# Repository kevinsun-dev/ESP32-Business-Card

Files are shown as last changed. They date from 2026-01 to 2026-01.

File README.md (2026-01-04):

# ESP32 Business Card Web Server

PCB Business Card

**A 0.8mm thick PCB business card that hosts its own website.**

This repository contains the KiCad hardware design files and the PlatformIO firmware source code for a custom PCB business card. The card features a built-in ESP32-C3 microcontroller, a PCB-edge USB-C connector, and enough flash memory to host a compressed version of my personal portfolio website.

**[Read the full write-up here.](https://kevinsun.dev/blog/pcb-business-card)**

## ⚡ Features

* **Self-Hosting:** Runs a full HTTP web server directly on the card.
* **Optimized:** Uses **LittleFS** and **GZIP compression** to serve a <14kB website with minimal latency.
* **Cost-Effective:** BOM target under **$5** using the ESP32-C3FH4.

## 🛠 Hardware Design

The hardware is designed around the **Espressif ESP32-C3FH4**, a RISC-V microcontroller with built-in 4MB flash, chosen for its low component count and ease of use.

### Key Specs

* **MCU:** ESP32-C3FH4 (RISC-V, 160MHz, WiFi/BLE)
* **Connector:** [PCB-Edge USB-C](https://github.com/AnasMalas/pcb-edge-usb-c) (Reversible)
* **PCB Thickness:** 0.8mm (Critical for USB-C fit)
* **Finish:** ENIG (Electroless Nickel Immersion Gold) for durability and aesthetics.

## 💻 Firmware

The firmware is built using **PlatformIO** with the **Arduino Framework** atop **ESP-IDF**.

### Key Capabilities

* **LittleFS Filesystem:** Decouples the website content from the C++ firmware logic.
* **GZIP Compression:** All web assets are pre-compressed (gzip) to reduce transmission size (~5kB) and load times.
* **OTA Updates:** The website and firmware can be updated wirelessly without plugging the card back into a programmer.
* **Dynamic Routing:** Automatically maps URLs (e.g., `/about`) to their corresponding compressed files (`/about.html.gz`).

## 🚀 Getting Started

### 1. Build the Hardware

Generate gerbers for your PCB using the KiCad files in this repository and assemble the components listed in the BOM.

### 2. Flash the Firmware

1. Install [PlatformIO](https://platformio.org/).
2. Clone this repository.
3. Connect the board via USB (hold the BOOT button while plugging in to enter bootloader mode).
4. Upload the firmware:
```bash
pio run --target upload
```

### 3. Upload the Website

The website files live in the `data/` folder. You must upload the filesystem image separately from the code.

```bash
# Compress your site and place in data/
# Then run:
pio run --target uploadfs
```

## 🌐 Live Demo

I've set up an ESP32 webserver hosting a mirror of my website 24/7.

* **Card Site:** [https://card.kevinsun.dev](https://card.kevinsun.dev)
* **Card Status:** [https://card.kevinsun.dev/status](https://www.google.com/url?sa=E&source=gmail&q=https://card.kevinsun.dev/status) (Tunneled via Cloudflare)

## 📄 License

* **Hardware:** Creative Commons Attribution-ShareAlike 4.0 (CC BY-SA 4.0)
* **Firmware:** MIT License

## 🙌 Credits & Inspiration

* **[mitxela](https://mitxela.com/projects/stylocard):** For the original StyloCard inspiration.
* **[Anas Malas](https://github.com/AnasMalas/pcb-edge-usb-c):** For the PCB-edge USB-C footprint design.
* **Kevin Sun:** Project Creator.

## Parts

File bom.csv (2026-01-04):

Comment | Designator | Footprint | LCSC
USBLC6-2SC6 | U3 | Package_TO_SOT_SMD:SOT-23-6
BOOT | SW2 | TS-1187A-B-A-B:SW_TS-1187A-B-A-B
5k1 | R1,R2,R3,R4,R6,R7 | Resistor_SMD:R_0402_1005Metric
100nF | C1,C2,C5,C6,C13,C14,C17,C18,C20 | Capacitor_SMD:C_0402_1005Metric
GPIO Breakout | J2 | Connector_PinHeader_2.54mm:PinHeader_1x08_P2.54mm_Vertical
10nF | C8 | Capacitor_SMD:C_0402_1005Metric
CPU | D3 | LED_SMD:LED_0603_1608Metric
1.5pF | C11,C12 | Capacitor_SMD:C_0402_1005Metric_Pad0.74x0.62mm_HandSolder
AMS1117-3.3 | U4 | Package_TO_SOT_SMD:SOT-223-3_TabPin2
2.4nH | L1 | Inductor_SMD:L_0402_1005Metric
2.4nH | L2,L3 | Inductor_SMD:L_0402_1005Metric_Pad0.77x0.64mm_HandSolder
WiFi | D2 | LED_SMD:LED_0603_1608Metric
12p | C9,C10 | Capacitor_SMD:C_0402_1005Metric
RESET | SW1 | TS-1187A-B-A-B:SW_TS-1187A-B-A-B
L327S400H11L | Y1 | Crystal:Crystal_SMD_3225-4Pin_3.2x2.5mm
1k | R5,R8,R9,R10 | Resistor_SMD:R_0402_1005Metric
10uF | C3,C15,C16 | Capacitor_SMD:C_0402_1005Metric
150pF | C19 | Capacitor_SMD:C_0402_1005Metric_Pad0.74x0.62mm_HandSolder
1uF | C4,C7 | Capacitor_SMD:C_0402_1005Metric
PWR | D1 | LED_SMD:LED_0603_1608Metric
ESP32-C3FH4 | U1 | Package_DFN_QFN:QFN-32-1EP_5x5mm_P0.5mm_EP3.7x3.7mm
NT3H2111W0FHKH | U2 | C710403:C710403

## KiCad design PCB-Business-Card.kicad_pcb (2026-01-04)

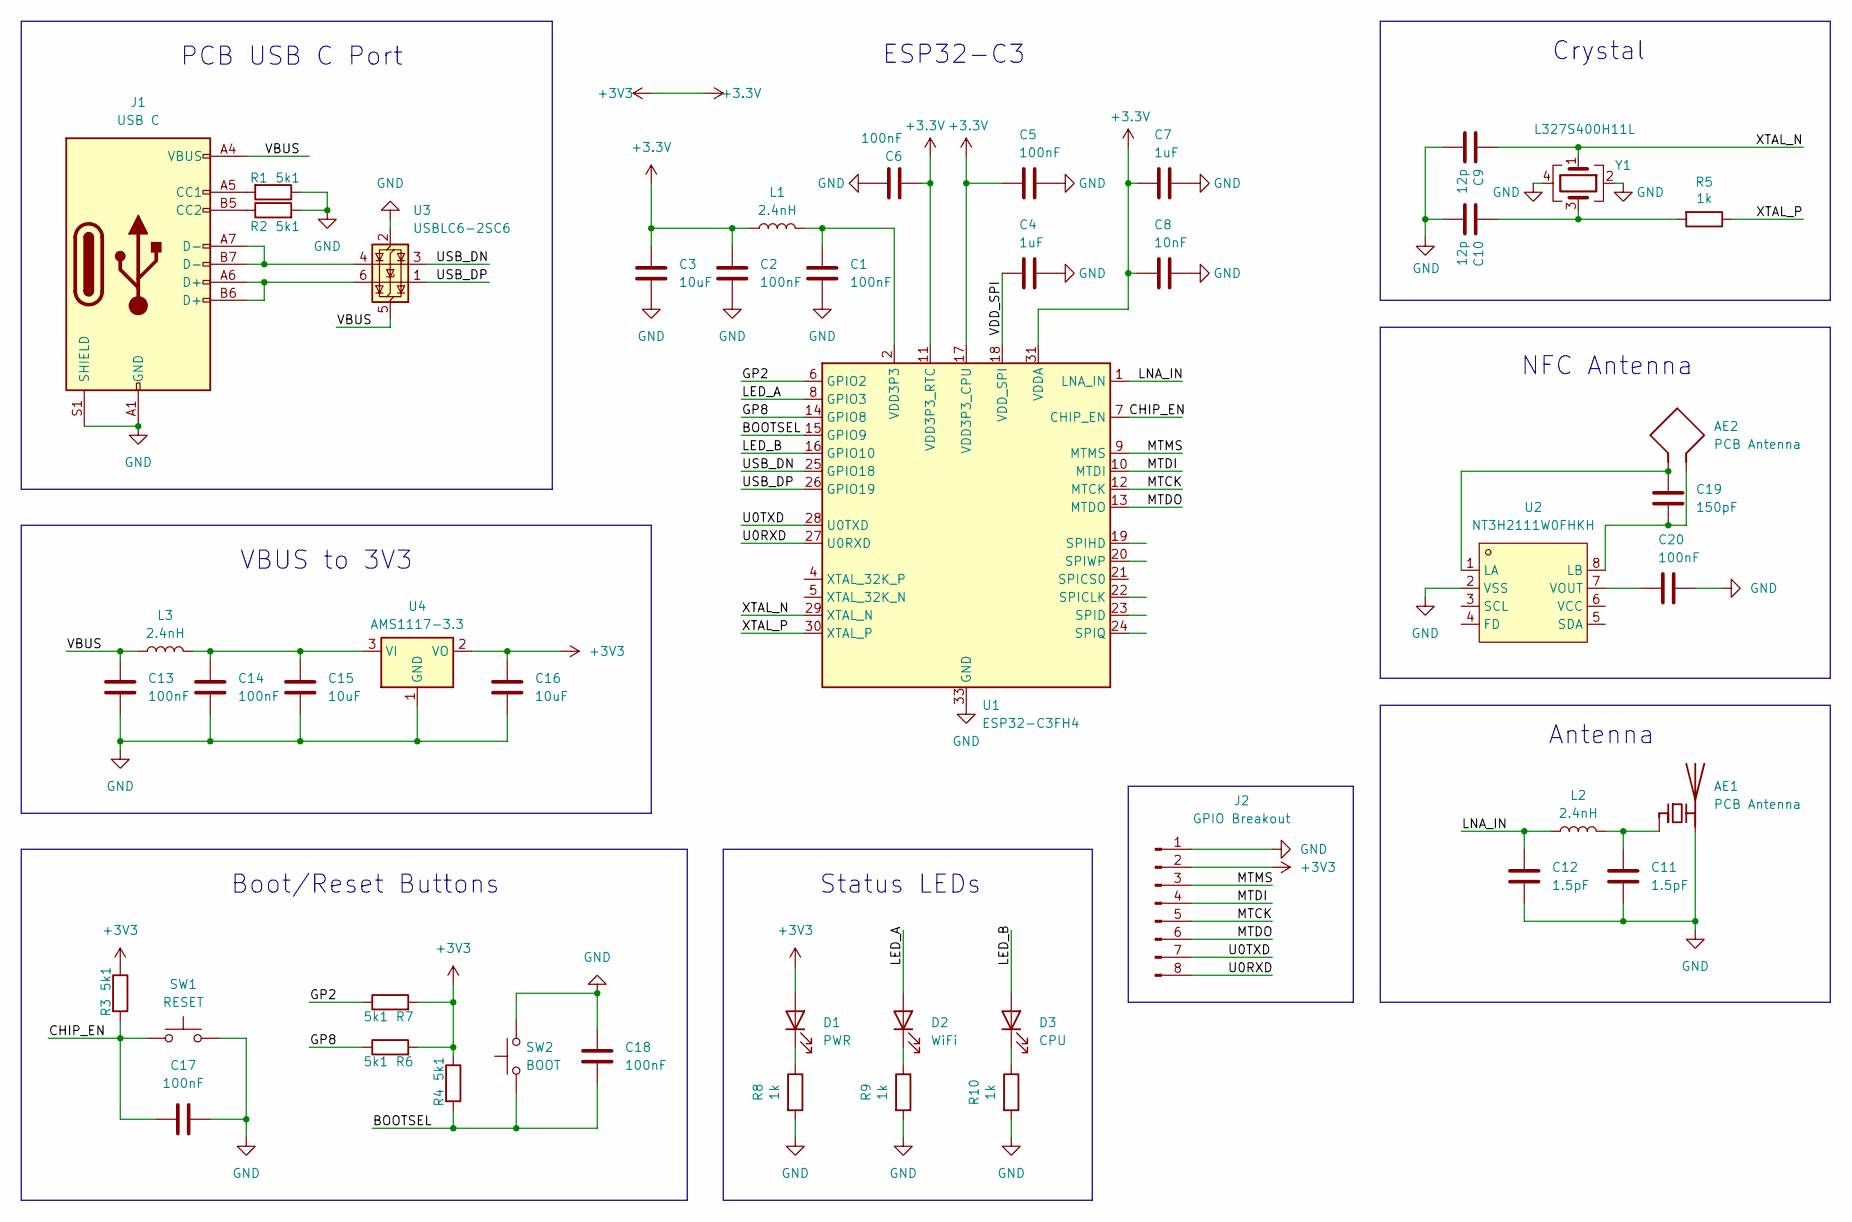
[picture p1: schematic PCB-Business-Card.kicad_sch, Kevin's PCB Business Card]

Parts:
AE1: PCB Antenna; pcb-antenna
AE2: PCB Antenna
C1, C2, C5, C6, C13, C14, C17, C18, C20: 100nF; C_0402_1005Metric; JLCPCB C1525
C3, C15, C16: 10uF; C_0402_1005Metric; JLCPCB C15525
C4, C7: 1uF; C_0402_1005Metric; JLCPCB C52923
C8: 10nF; C_0402_1005Metric; JLCPCB C15195
C9, C10: 12p; C_0402_1005Metric
C11, C12: 1.5pF; C_0402_1005Metric_Pad0.74x0.62mm_HandSolder; JLCPCB C1552
C19: 150pF; C_0402_1005Metric_Pad0.74x0.62mm_HandSolder
D1: PWR; LED_0603_1608Metric; JLCPCB C2286
D2: WiFi; LED_0603_1608Metric; JLCPCB C2290
D3: CPU; LED_0603_1608Metric; JLCPCB C89811
J1: USB C; PCBTypeC_24P
J2: GPIO Breakout; PinHeader_1x08_P2.54mm_Vertical
L1: 2.4nH; L_0402_1005Metric; JLCPCB C97997
L2, L3: 2.4nH; L_0402_1005Metric_Pad0.77x0.64mm_HandSolder; JLCPCB C97997
R1, R2, R3, R4, R6, R7: 5k1; R_0402_1005Metric; JLCPCB C25905
R5, R8, R9, R10: 1k; R_0402_1005Metric; JLCPCB C11702
SW1: RESET; SW_TS-1187A-B-A-B; JLCPCB C318884
SW2: BOOT; SW_TS-1187A-B-A-B; JLCPCB C318884
U1: ESP32-C3FH4; QFN-32-1EP_5x5mm_P0.5mm_EP3.7x3.7mm; JLCPCB C2858491
U2: NT3H2111W0FHKH; C710403; LCSC Part C710403
U3: USBLC6-2SC6; SOT-23-6; JLCPCB C2687116
U4: AMS1117-3.3; SOT-223-3_TabPin2; JLCPCB C6186
Y1: L327S400H11L; Crystal_SMD_3225-4Pin_3.2x2.5mm; JLCPCB C5261245

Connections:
+3.3V: C2.1, C3.1, C5.1, C6.1, C7.1, C8.1, C16.1, D1.2 (A), J2.2, L1.1, R3.1, R4.1, R6.2, R7.2, U1.11 (VDD3P3_RTC), U1.17 (VDD3P3_CPU), U1.31 (VDDA), U1.32 (VDDA), U4.2 (VO)
/BOOTSEL: C18.1, R4.2, SW2.1, U1.15 (GPIO9)
/CHIP_EN: C17.1, R3.2, SW1.1, U1.7 (CHIP_EN)
/GP2: R7.1, U1.6 (GPIO2)
/GP8: R6.1, U1.14 (GPIO8)
/LED_A: D2.2 (A), U1.8 (GPIO3)
/LED_B: D3.2 (A), U1.16 (GPIO10)
/LNA_IN: C12.1, L2.1, U1.1 (LNA_IN)
/MTCK: J2.5, U1.12 (MTCK)
/MTDI: J2.4, U1.10 (MTDI)
/MTDO: J2.6, U1.13 (MTDO)
/MTMS: J2.3, U1.9 (MTMS)
/U0RXD: J2.8, U1.27 (U0RXD)
/U0TXD: J2.7, U1.28 (U0TXD)
/USB_DN: U1.25 (GPIO18), U3.3 (I/O2)
/USB_DP: U1.26 (GPIO19), U3.1 (I/O1)
/VBUS: C13.1, J1.A4 (VBUS), J1.A9 (VBUS), J1.B4 (VBUS), J1.B9 (VBUS), L3.1, U3.5 (VBUS)
/VDD_SPI: C4.1, U1.18 (VDD_SPI)
/XTAL_N: C9.1, U1.29 (XTAL_N), Y1.1
/XTAL_P: R5.1, U1.30 (XTAL_P)
GND: AE1.2 (PCB_Trace), C1.2, C2.2, C3.2, C4.2, C5.2, C6.2, C7.2, C8.2, C9.2, C10.2, C11.2, C12.2, C13.2, C14.2, C15.2, C16.2, C17.2, C18.2, C20.2, J1.A1 (GND), J1.A12 (GND), J1.B1 (GND), J1.B12 (GND), J1.S1 (SHIELD), J2.1, R1.1, R2.2, R8.2, R9.2, R10.2, SW1.2, SW2.2, U1.33 (GND), U2.2 (VSS), U3.2 (GND), U4.1 (GND), Y1.2, Y1.4
unnamed: AE1.1 (FEED), C11.1, L2.2
unnamed: C1.1, L1.2, U1.2 (VDD3P3), U1.3 (VDD3P3)
unnamed: C10.1, R5.2, Y1.3
unnamed: D1.1 (K), R8.1
unnamed: D2.1 (K), R9.1
unnamed: D3.1 (K), R10.1
unnamed: J1.A5 (CC1), R1.2
unnamed: J1.B5 (CC2), R2.1
unnamed: J1.A6 (D+), J1.B6 (D+), U3.6 (I/O1)
unnamed: J1.A7 (D-), J1.B7 (D-), U3.4 (I/O2)
unnamed: AE2.1, C19.1, U2.1 (LA)
unnamed: AE2.2, C19.2, U2.8 (LB)
unnamed: C20.1, U2.7 (VOUT)
unnamed: C14.1, C15.1, L3.2, U4.3 (VI)

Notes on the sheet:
NFC Antenna
ESP32-C3
VBUS to 3V3
Crystal
Boot/Reset Buttons
PCB USB C Port
Status LEDs
Antenna

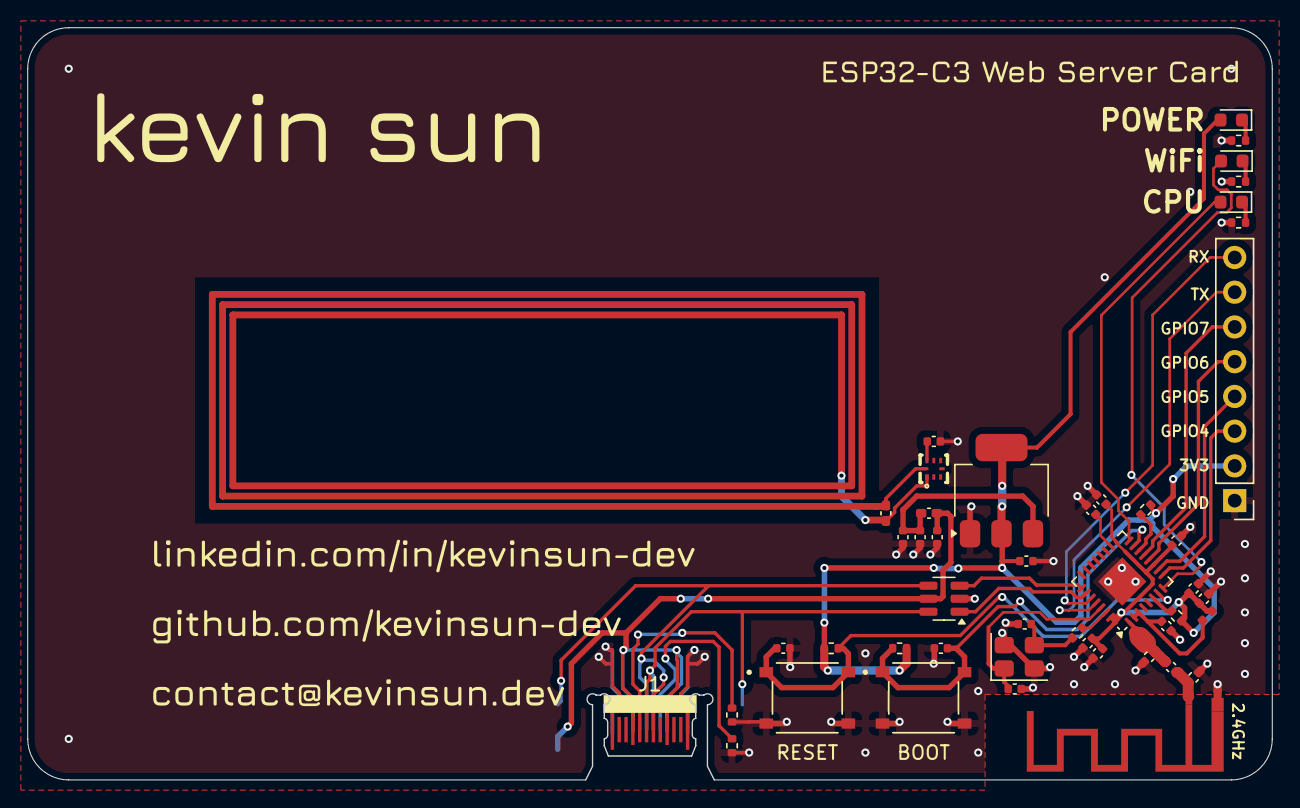
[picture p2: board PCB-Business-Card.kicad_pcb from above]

Board: 2 copper layers, 91.0 x 55.0 mm, 46 parts (0 on the bottom side), 35 nets.

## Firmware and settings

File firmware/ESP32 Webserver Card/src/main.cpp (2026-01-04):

#include <Arduino.h>
#include <ESPmDNS.h>
#include <LittleFS.h>
#include <NetworkClient.h>
#include <WebServer.h>
#include <WiFi.h>
#include <secrets.h>

const char* ssid = WIFI_SSID;
const char* password = WIFI_PWD;
const char* ota_secret = OTA_PWD;

WebServer server(80);
const int led = 13;

// --- PERSISTENCE SETTINGS ---
const char* STATS_FILE = "/stats.bin";
const unsigned long SAVE_INTERVAL_MS = 3600000;  // 1 Hour
unsigned long lastSaveTime = 0;

// Struct to hold data we want to save
struct PersistentStats {
    uint64_t totalVisits;  // 64-bit to prevent overflow
    uint64_t totalResponseTimeMs;
    uint64_t totalRuntimeSeconds;  // Cumulative time across all boots
};

PersistentStats stats = {0, 0, 0};

// Helper: Secure OTA Auth Check
bool isAuthorized() {
    if (server.arg("token") == ota_secret) return true;
    return false;
}

// Helper: Secure OTA Upload
File uploadFile;
bool uploadAccepted = false;

void handleFileUpload() {
  HTTPUpload& upload = server.upload();
  
  // 1. START
  if (upload.status == UPLOAD_FILE_START) {
    if (!isAuthorized()) {
      Serial.println("Unauthorized upload attempt blocked.");
      uploadAccepted = false;
      return;
    }

    String filename = upload.filename;
    if (!filename.startsWith("/")) filename = "/" + filename;
    Serial.print("Receiving file: "); Serial.println(filename);
    
    uploadFile = LittleFS.open(filename, "w");
    uploadAccepted = true;
    filename = String();
  } 
  
  // 2. WRITE (The Danger Zone)
  else if (upload.status == UPLOAD_FILE_WRITE) {
    if (uploadAccepted && uploadFile) {
      size_t bytesWritten = uploadFile.write(upload.buf, upload.currentSize);
      
      // CRITICAL CHECK: Did we actually write everything?
      if (bytesWritten != upload.currentSize) {
         Serial.println("Write Failed!");
         // Optional: Abort logic
      }
      
      // FIX: Feed the Watchdog!
      yield(); 
    }
  } 
  
  // 3. END
  else if (upload.status == UPLOAD_FILE_END) {
    if (uploadAccepted && uploadFile) {
      uploadFile.close();
      Serial.print("Upload Size: "); Serial.println(upload.totalSize);
      
      // Force a slight delay to ensure Serial finishes before any potential redirect logic
      delay(2); 
    }
  }
}

// Helper: Secure OTA Complete
void handleUploadResponse() {
    if (!isAuthorized()) {
        server.send(401, "text/plain", "Unauthorized");
    } else {
        server.sendHeader("Location", "/status");
        server.send(303);
    }
}

// Helper: Save to Flash
void saveStats() {
    File file = LittleFS.open(STATS_FILE, "w");
    if (!file) {
        Serial.println("Failed to open stats file for writing");
        return;
    }

    // Update the runtime before saving
    file.write((uint8_t*)&stats, sizeof(stats));
    file.close();
    Serial.println("Stats saved to flash.");
}

// Helper: Load from Flash
void loadStats() {
    if (LittleFS.exists(STATS_FILE)) {
        File file = LittleFS.open(STATS_FILE, "r");
        if (file) {
            file.read((uint8_t*)&stats, sizeof(stats));
            file.close();
            Serial.println("Stats loaded from flash.");

            Serial.print("Previous Visits: ");
            Serial.println(stats.totalVisits);
            Serial.print("Previous Runtime: ");
            Serial.println((unsigned long)stats.totalRuntimeSeconds);
        }
    } else {
        Serial.println("No saved stats found. Starting fresh.");
    }
}

// Helper: Format time for display (e.g., "5d 12h:30m:05s")
String formatTime(unsigned long long totalSeconds) {
    unsigned long long sec = totalSeconds;
    unsigned long long min = sec / 60;
    unsigned long long hr = min / 60;
    unsigned long long day = hr / 24;

    char buffer[64];
    snprintf(buffer, sizeof(buffer), "%llud %02lluh:%02llum:%02llus", day, hr % 24, min % 60, sec % 60);
    return String(buffer);
}

// Helper: Returns a content type for various file types
String getContentType(String filename) {
    if (server.hasArg("download"))
        return "application/octet-stream";
    else if (filename.endsWith(".html"))
        return "text/html";
    else if (filename.endsWith(".css"))
        return "text/css";
    else if (filename.endsWith(".js"))
        return "application/javascript";
    else if (filename.endsWith(".png"))
        return "image/png";
    else if (filename.endsWith(".gif"))
        return "image/gif";
    else if (filename.endsWith(".jpg"))
        return "image/jpeg";
    else if (filename.endsWith(".ico"))
        return "image/x-icon";
    else if (filename.endsWith(".xml"))
        return "text/xml";
    else if (filename.endsWith(".pdf"))
        return "application/x-pdf";
    else if (filename.endsWith(".zip"))
        return "application/x-zip";
    return "text/plain";
}

// --- DYNAMIC FILE SERVER ---
// This function tries to find a file matching the request URL
bool handleDynamicRequest() {
    String path = server.uri();

    // Handle root
    if (path.endsWith("/")) path += "index";

    // Prepare standard paths
    String pathWithGz = path + ".gz";
    String contentType = getContentType(path);

    // --- STRATEGY 1: Exact Match (e.g. /style.css or /image.png) ---
    // We check for a .gz version first to save bandwidth
    if (LittleFS.exists(pathWithGz) || LittleFS.exists(path)) {
        bool isGzipped = LittleFS.exists(pathWithGz);
        String fullPath = isGzipped ? pathWithGz : path;

        File file = LittleFS.open(fullPath, "r");
        if (!file) return false;

        digitalWrite(led, 1);
        unsigned long startTick = millis();

        server.streamFile(file, contentType);

        unsigned long duration = millis() - startTick;
        stats.totalVisits++;
        stats.totalResponseTimeMs += duration;

        file.close();
        digitalWrite(led, 0);
        return true;
    }

    // --- STRATEGY 2: HTML Fallback (e.g. /about -> /about.html) ---
    // Only try this if the path has no extension
    if (path.lastIndexOf('.') <= path.lastIndexOf('/')) {
        String htmlPath = path + ".html";
        String htmlPathGz = htmlPath + ".gz";

        if (LittleFS.exists(htmlPathGz) || LittleFS.exists(htmlPath)) {
            bool isGzipped = LittleFS.exists(htmlPathGz);
            String fullPath = isGzipped ? htmlPathGz : htmlPath;

            File file = LittleFS.open(fullPath, "r");
            if (!file) return false;

            digitalWrite(led, 1);
            unsigned long startTick = millis();

            server.streamFile(file, "text/html");

            unsigned long duration = millis() - startTick;
            stats.totalVisits++;
            stats.totalResponseTimeMs += duration;

            file.close();
            digitalWrite(led, 0);
            return true;
        }
    }

    return false;
}

void handleNotFound() {
    if (handleDynamicRequest()) return;

    String message = "404 Not Found\n\nURI: " + server.uri();
    server.send(404, "text/plain", message);
}

void handleStatus() {
    digitalWrite(led, 1);

    // Calculate averages
    float avgTime = (stats.totalVisits > 0)
                        ? (float)stats.totalResponseTimeMs / stats.totalVisits
                        : 0;

    // Calculate Runtimes
    unsigned long currentSessionSecs = millis() / 1000;
    uint64_t totalLifetimeSecs = stats.totalRuntimeSeconds + currentSessionSecs;

    String json = "{";
    json += "\"uptime_session\": \"" + formatTime(currentSessionSecs) + "\",";
    json += "\"uptime_lifetime\": \"" + formatTime(totalLifetimeSecs) + "\",";
    json += "\"visits\": " + String((unsigned long)stats.totalVisits) + ",";
    json += "\"avg_response_time_ms\": " + String(avgTime, 1) + ",";
    json += "\"free_heap_bytes\": " + String(ESP.getFreeHeap()) + ",";
    json += "\"wifi_signal_dbm\": " + String(WiFi.RSSI()) + ",";
    json += "\"status\": \"online\"";
    json += "}";

    server.send(200, "application/json", json);
    digitalWrite(led, 0);
}

void setup(void) {
    pinMode(led, OUTPUT);
    digitalWrite(led, 0);
    Serial.begin(115200);

    if (!LittleFS.begin()) {
        Serial.println("Error mounting LittleFS");
        return;
    }

    // LOAD STATS ON BOOT
    loadStats();

    WiFi.mode(WIFI_STA);
    WiFi.begin(ssid, password);

    while (WiFi.status() != WL_CONNECTED) {
        delay(500);
        Serial.print(".");
    }

    WiFi.setSleep(false);
    Serial.println("\nConnected.");
    Serial.println(WiFi.localIP());

    if (MDNS.begin("esp32")) {
        Serial.println("MDNS responder started");
    }

    server.on("/status", handleStatus);
    server.on("/update", HTTP_POST, handleUploadResponse, handleFileUpload);

    server.onNotFound(handleNotFound);

    server.begin();
    Serial.println("HTTP server started");
}

void loop(void) {
    server.handleClient();
    delay(2);

    // --- PERIODIC SAVE (EVERY 1 HOUR) ---
    if (millis() - lastSaveTime >= SAVE_INTERVAL_MS) {
        unsigned long currentMillis = millis();
        unsigned long elapsedSinceLastSave = currentMillis - lastSaveTime;

        stats.totalRuntimeSeconds += (elapsedSinceLastSave / 1000);

        saveStats();

        lastSaveTime = currentMillis;
    }
}

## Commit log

2025-11-09 Wrote new Edge Cuts
    [PCB-Business-Card.kicad_pcb, panel.kicad_pcb, panel.kicad_sch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]
2025-11-09 Working Panel (does not satisfy JLCPCB economic assembly reqs)
    [PCB-Business-Card.kicad_pcb, bom.csv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]
2025-11-10 Improved Solder Mask Margin
    [PCB-Business-Card.kicad_pcb]
2025-11-10 Added Economic PCB option
    [PCB-Business-Card-Economic.kicad_pcb, PCB-Business-Card-Economic.kicad_sch]
2025-11-18 Final Tapeout Version
    [PCB-Business-Card.kicad_pcb, PCB-Business-Card.kicad_sch, bom.csv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]
2026-01-04 Added README and firmware
    [PCB-Business-Card.kicad_pcb, PCB-Business-Card.kicad_sch]
